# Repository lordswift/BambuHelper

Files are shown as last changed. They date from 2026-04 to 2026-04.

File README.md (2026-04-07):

# BambuHelper

Dedicated Bambu Lab printer monitor built with ESP32-S3 Super Mini and a 1.54" 240x240 color TFT display (ST7789).

Connects to your printer via MQTT over TLS and displays a real-time dashboard with arc gauges, animations, live stats, and optional buzzer notifications.

Beta support for CYD 320x240 displays is also available.

### Supported Printers

| Connection Mode | Printers | How it connects |
|---|---|---|
| **LAN Direct** | P1P, P1S, X1, X1C, X1E, A1, A1 Mini | Local MQTT via printer IP + LAN access code |
| **LAN Direct (Developer Mode)** | H2S, H2C, H2D | LAN-only mode + Developer Mode required - see note below |
| **Bambu Cloud (All printers)** | Any Bambu printer | Cloud MQTT via access token - no LAN mode needed |

> **H2 series LAN mode:** H2S, H2C, and H2D printers require both **LAN-only mode** and **Developer Mode** enabled in printer settings for local MQTT to work. Without Developer Mode, the printer accepts connections but does not respond to status requests. If you prefer not to enable Developer Mode, use Bambu Cloud mode instead.

> **Tip:** Use "Bambu Cloud (All printers)" if you don't want to enable LAN/Developer mode on your printer (for example to keep Bambu Handy working), if your ESP32 is on a different network than the printer, or if your printer only supports cloud mode (P2S).

### Cloud Mode Security Notice

When using Bambu Cloud, BambuHelper connects through Bambu Lab's cloud MQTT service. Here is what you need to know:

- **No credentials are stored** - BambuHelper never asks for your email or password. You extract an access token from your browser and paste it into the web interface.
- **Only the access token is stored** in the ESP32's flash memory. This token expires after about 3 months, at which point you simply paste a new one.
- **Read-only access** - BambuHelper only reads printer status. It never sends commands or modifies printer settings.
- **Same approach as other community projects** - this is the same authentication method used by the [Home Assistant Bambu Lab integration](https://github.com/greghesp/ha-bambulab), [OctoPrint-Bambu](https://github.com/jneilliii/OctoPrint-BambuPrinter), and other trusted third-party tools.

## Screenshots

| Dashboard | Web Interface - Settings | Web Interface - Gauge Colors |
|---|---|---|
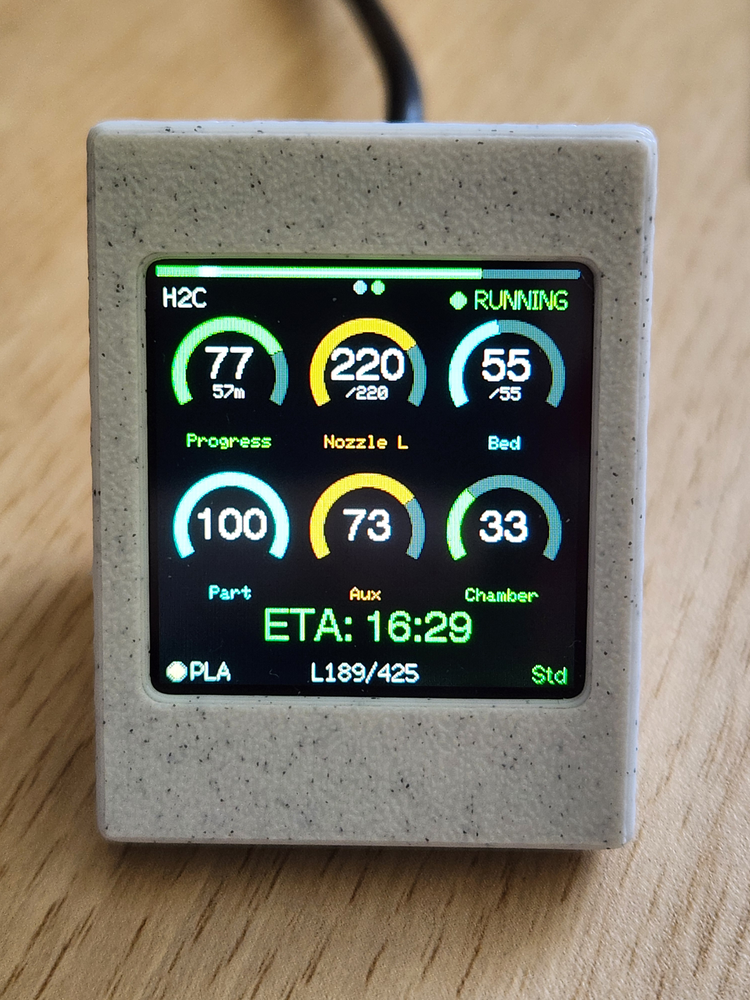
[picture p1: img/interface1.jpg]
Dashboard
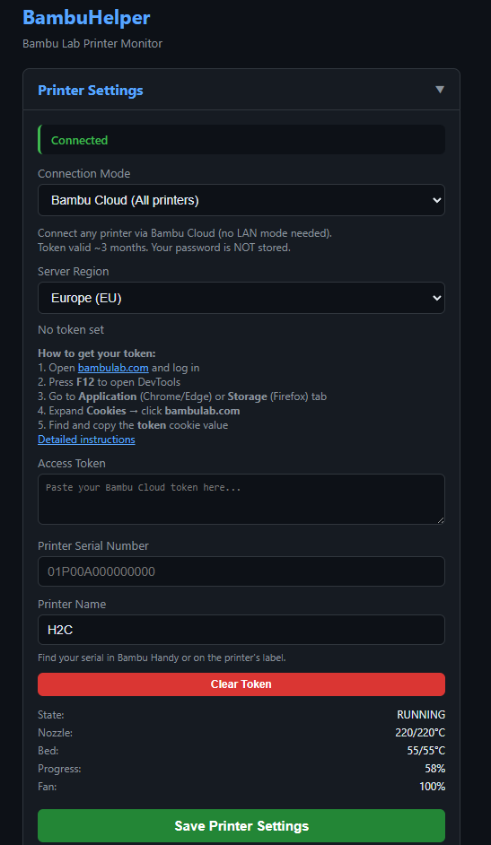
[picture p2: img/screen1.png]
Settings
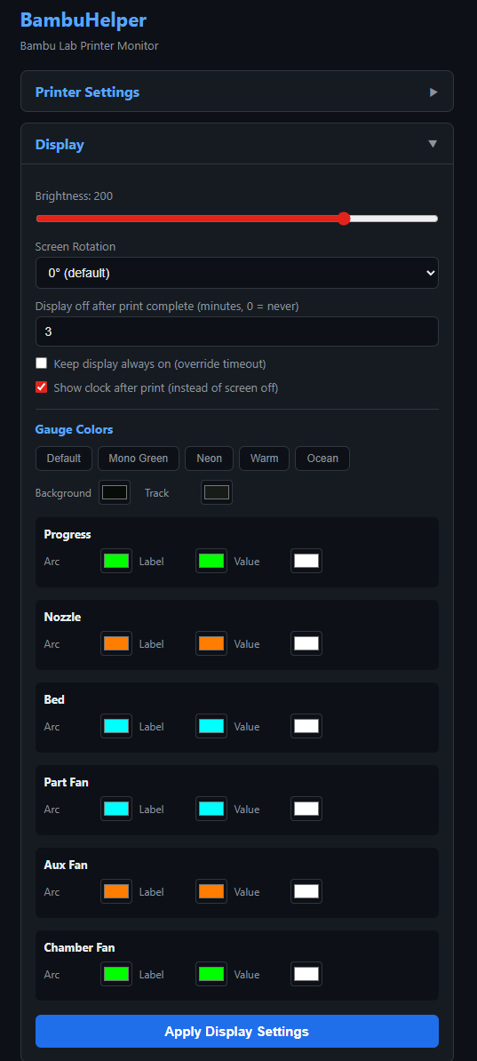
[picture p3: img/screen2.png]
Gauge Colors
|  |  |  |

## CYD Display Support (Beta)

| Preview | Notes |
|---|---|
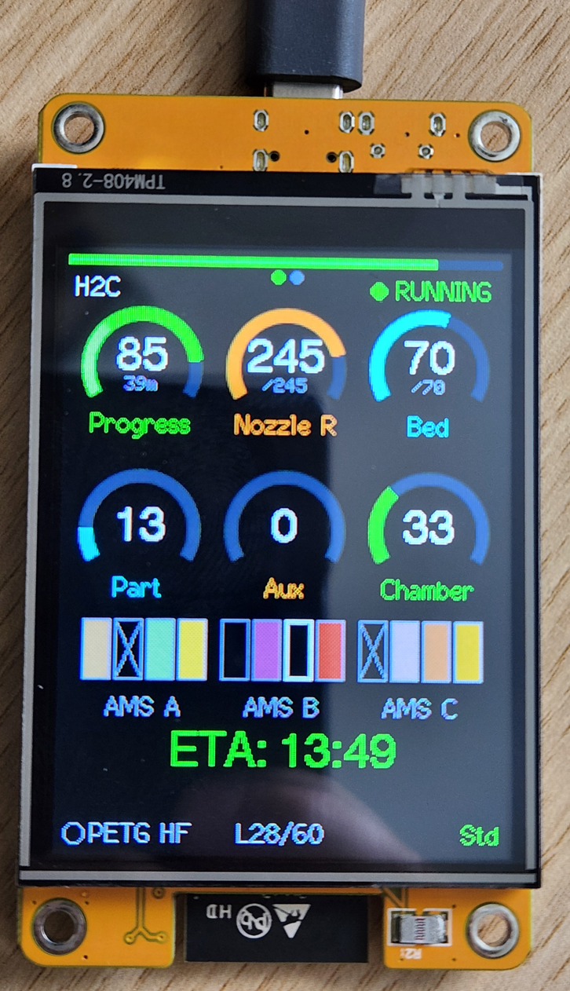
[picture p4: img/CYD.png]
CYD display
|  | **CYD / ESP32-2432S028** support is available and currently **beta**. This is the larger `320x240` display version. Flashing is done the same way as the standard `240x240` build, but on [ESP Web Flasher](https://espressif.github.io/esptool-js/) you should set **Baudrate: 115200** before clicking **Connect**. This low baudrate note is for **CYD only**. The standard ESP32-S3 240x240 version does not require this change. Tested behavior so far: The first connection attempt may fail - click **Disconnect** in the web tool, then **Connect** again and it should work on the second try. **Do not physically unplug the USB cable between attempts** - just use the buttons in the web flasher. [Use this firmware](https://github.com/Keralots/BambuHelper/releases/download/v2.5/BambuHelper-cyd-v2.5-Full.bin) If the display colors appear reversed (white background instead of dark), go to the web interface under **Display** and enable **Invert display colors (fix white background)**. |

## Features

- **Live dashboard** - progress arc, temperature gauges, fan speed, layer count, time remaining
- **H2-style LED progress bar** - full-width glowing bar inspired by Bambu H2 series
- **Anti-aliased arc gauges** - smooth nozzle and bed temperature arcs with color zones
- **Animations** - loading spinner, progress pulse, completion celebration
- **Web config portal** - dark-themed settings page for WiFi, network, printer, display, power, and buzzer settings
- **Network configuration** - DHCP or static IP, with optional IP display at startup
- **Display auto-off** - configurable timeout after print completion, auto-off when printer is off
- **NVS persistence** - all settings survive reboots
- **Auto AP mode** - creates WiFi hotspot on first boot or when WiFi is lost
- **Smart redraw** - only redraws changed UI elements for smooth performance
- **Customizable gauge colors** - per-gauge arc/label/value colors with preset themes
- **Multi-printer support** - monitor up to 2 printers simultaneously with auto-rotating display (ESP32-S3 only - CYD/C3 limited to 1 printer due to RAM)
- **Smart rotation** - automatically shows the printing printer; cycles between both when both are printing
- **Physical button** - optional push button or TTP223 touch sensor to cycle printers and wake display
- **Optional buzzer** - passive buzzer notifications for print finished, connected, and error events
- **OTA updates** - firmware can be updated from the web interface
- **CYD display support (beta)** - support for ESP32-2432S028 / 320x240 displays
- **Exponential backoff** - reconnect attempts to offline printers gradually slow down to conserve resources

## Hardware

| Component | Specification |
|---|---|
| MCU | ESP32-S3 Super Mini |
| Display | 1.54" TFT SPI ST7789 (240x240) |
| Optional display | CYD / ESP32-2432S028, 320x240 ILI9341 (beta) |
| Connection | SPI |

Display: 1.54": https://a.aliexpress.com/_EG9y7wc

ESP32-S3 SuperMini: https://a.aliexpress.com/_Eyk9GdA  (Make sure you purchase S3 variant!)

Optional: TTP223 touch button or standard push button for multi-printer switching (auto printer switching works without a button anyway; change settings in the web interface): TTP223 link: https://aliexpress.com/item/1005006246380749.html

Optional: Passive buzzer for print finish and error notifications: https://aliexpress.com/item/1005008825917787.html

Optional case seen on picture (for ST7789 (240x240) display): https://makerworld.com/en/models/2501721

### Default Wiring

| Display Pin ST7789 (240x240) | ESP32-S3 GPIO | ESP32-C3 GPIO |
|---|---|---|
| MOSI (SDA) | 11 | 20 |
| SCLK (SCL) | 12 | 21 |
| CS | 10 | 6 |
| DC | 9 | 7 |
| RST | 8 | 10 |
| BL | 13 | 5 |
| GND | GND | GND |
| VCC | 3.3V | 3.3V |

Adjust pin assignments in `platformio.ini` `build_flags` to match your wiring.

Touch TTP223 button is optional. It is used to switch between printers. You may also use a standard push button and connect it between pin 4 and GND, then pick the correct button type in the web interface under Multi-Printer support.

### Optional Touch Sensor / Button Wiring

A button or touch sensor is optional. It cycles between printers and wakes the display from sleep. Configure the type and GPIO in the web interface under **Multi-Printer**.

**TTP223 capacitive touch sensor:**

| TTP223 Pin | ESP32-S3 GPIO | ESP32-C3 GPIO |
|---|---|---|
| `VCC` | `3.3V` | `3.3V` |
| `GND` | `GND` | `GND` |
| `SIG` | `GPIO 4` | `GPIO 4` |

**Standard push button:** connect one leg to `GPIO 4` and the other to `GND`. The internal pull-up is enabled automatically. Select **Push Button** in the web interface.

### Optional Buzzer Wiring

The buzzer is completely optional. If you do not connect one, BambuHelper works normally.

Use a **passive buzzer** and connect it like this:

| Buzzer Pin | ESP32-S3 GPIO | ESP32-C3 GPIO |
|---|---|---|
| `+` / `SIG` | `GPIO 5` | `GPIO 3` |
| `-` / `GND` | `GND` | `GND` |

> **Note:** The firmware default buzzer pin is `GPIO 5` on both ESP32-S3 and ESP32-C3. The table above shows the **recommended wiring**. If you wire an ESP32-C3 buzzer to `GPIO 3`, you must change the buzzer pin to `GPIO 3` in the web interface after the first boot.
> **Note:** The firmware default buzzer pin is `GPIO 5` on both ESP32-S3 and ESP32-C3. The table above shows the **recommended wiring**. If you wire an ESP32-C3 buzzer to `GPIO 3`, you must change the buzzer pin to `GPIO 3` in the web interface after the first boot.
You can change the buzzer GPIO later in the web interface under **Buzzer**. The buzzer can be used for print-finished, connected, and error notifications.

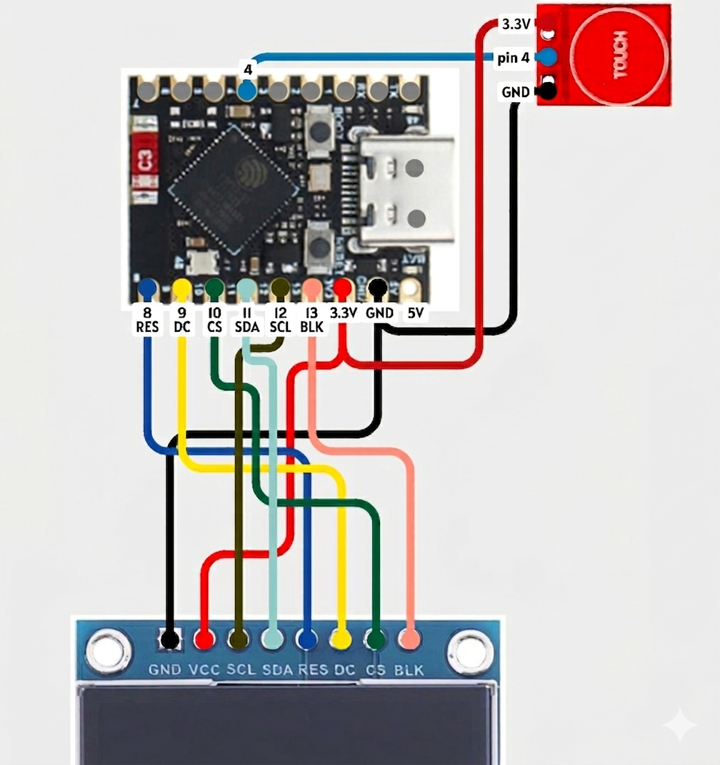
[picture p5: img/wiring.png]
wiring


### Assembly Video

Assembly Video (https://youtu.be/hsyamsU5UZE)

## Flashing

1. Download the latest firmware from [Releases](../../releases). **If you are flashing a new device for the first time**, use the file ending with **-Full** (e.g. `BambuHelper-WebFlasher-v2.5-Full.bin`). The regular (non-Full) file is for OTA updates on devices that already have BambuHelper installed.
2. Open [ESP Web Flasher](https://espressif.github.io/esptool-js/) in Chrome or Edge
3. If you are flashing a **CYD**, set **Baudrate** to **115200** before clicking **Connect**. Two or more attempts may be needed - the first one will fail. This applies to **CYD only**.
4. Connect your ESP32 via USB
5. Click **Connect** and select your device
6. Set flash address to **0x0**
7. Select the downloaded `.bin` file
8. Click **Program**

## Setup

### Configuration Guide

Configuration Guide (https://youtu.be/n2RdbeHTMz0)

1. **Flash** the firmware (see above)
2. **Connect** to the `BambuHelper-XXXX` WiFi network (password: `bambu1234`)
3. **Open** `192.168.4.1` in your browser
4. **Enter** your home WiFi credentials and **Save** - the device restarts and connects to your WiFi
5. **Note the IP address** shown on the ESP32 display after it connects to WiFi
6. **Open** that IP address in your browser to access the full web interface
7. **Configure your printer:**

   **LAN Direct** (P1P, P1S, X1, X1C, X1E, A1, A1 Mini):
   - Printer IP address (found in printer Settings > Network)
   - Serial number (see note below)
   - LAN access code (8 characters, from printer Settings > Network)

   **Bambu Cloud (All printers)**:
   - Get your Bambu Cloud access token from your browser (see [Getting a Cloud Token](#getting-a-cloud-token) below)
   - Paste the token into the web interface
   - Enter your printer's serial number (see note below)

   > **Important: Serial number is NOT the printer name.** The serial number is a 15-character code (for example `01P00A000000000`) found on the printer LCD under **Settings > Device > Serial Number**, or on the physical label on the back or bottom of the printer. Do not confuse it with the printer name shown in Bambu Studio (for example `3DP-01P-110`), which is a shortened version and will not work.

8. **Save Printer Settings** - the device connects to your printer

### Getting a Cloud Token

To use cloud mode, you need an access token from your Bambu Lab account. There are two ways to get it:

**Using browser DevTools (Chrome / Edge):**
1. Open https://bambulab.com and log in to your account
2. Press **F12** to open DevTools
3. Go to the **Application** tab (click `>>` if you do not see it)
4. In the left sidebar, expand **Cookies** -> click `https://bambulab.com`
5. Find the row named `token` in the cookie list
6. Double-click the **Value** cell to select it, then **Ctrl+C** to copy
7. Paste the value into BambuHelper's "Access Token" field in the web interface

**Using browser DevTools (Firefox):**
1. Open https://bambulab.com and log in to your account
2. Press **F12** to open DevTools
3. Go to the **Storage** tab
4. In the left sidebar, expand **Cookies** -> click `https://bambulab.com`
5. Find the row named `token`
6. Double-click the **Value** cell to select it, then **Ctrl+C** to copy
7. Paste the value into BambuHelper's "Access Token" field

**Using browser DevTools (Safari):**
1. Open https://bambulab.com and log in to your account
2. Open **Develop** -> **Show Web Inspector** (enable the Develop menu first in Safari Preferences -> Advanced)
3. Go to the **Storage** tab -> **Cookies** -> `bambulab.com`
4. Find and copy the `token` value
5. Paste it into BambuHelper's "Access Token" field

**Using the Python helper script (recommended):**
```bash
pip install curl_cffi
python tools/get_token.py
```
The script will prompt for your email, password, and 2FA code, then print the token. Copy and paste it into BambuHelper's web interface.

> **Note:** The token is valid for approximately 3 months. When it expires, the ESP32 will fail to connect - simply repeat the process above to get a fresh token and paste it in the web interface. Make sure to select the correct **Server Region** (US/EU/CN) to match your Bambu account's region.

## Web Interface

The built-in web interface (accessible at the device's IP address) provides the following settings:

### WiFi Settings
- **SSID** - your home WiFi network name
- **Password** - WiFi password

### Network
- **IP Assignment** - choose between DHCP (automatic) or Static IP
- **Static IP fields** (when static is selected):
  - IP Address
  - Gateway
  - Subnet Mask
  - DNS Server
- **Show IP at startup** - display the assigned IP on screen for 3 seconds after WiFi connects (on by default)

### Printer Settings
- **Connection Mode** - LAN Direct or Bambu Cloud (All printers)
- **LAN mode fields:**
  - Printer Name, Printer IP Address, Serial Number, LAN Access Code
- **Cloud mode fields:**
  - Server Region (US/EU/CN), Access Token, Printer Serial Number, Printer Name
- **Live Stats** - real-time nozzle/bed temp, progress, fan speed, and connection status

### Display
- **Brightness** - backlight level (10-255)
- **Screen Rotation** - 0, 90, 180, 270 degrees
- **Display off after print complete** - minutes to show the finish screen before turning off the display (0 = never turn off, default: 3 minutes)
- **Keep display always on** - override the timeout and never turn off
- **Show clock after print** - display a digital clock with date instead of turning off the screen (enabled by default)

### Gauge Colors
- **Theme presets** - Default, Mono Green, Neon, Warm, Ocean
- **Background color** - display background
- **Track color** - inactive arc background
- **Per-gauge colors** (arc, label, value) for:
  - Progress
  - Nozzle temperature
  - Bed temperature
  - Part fan
  - Aux fan
  - Chamber fan

### Buzzer
- **Buzzer (optional)** - enable or disable passive buzzer notifications
- **GPIO Pin** - choose which ESP32 pin drives the buzzer
- **Quiet Hours** - disable buzzer sounds during selected hours
- **Test Buttons** - quickly test available buzzer sounds from the web interface

### Other
- **Factory Reset** - erases all settings and restarts
- **OTA Update** - update firmware directly from the web interface

## Dashboard Screens

| Screen | When |
|---|---|
| Splash | Boot (2 seconds) |
| AP Mode | First boot / no WiFi configured |
| Connecting WiFi | Attempting WiFi connection |
| WiFi Connected | Shows IP for 3 seconds (if enabled) |
| Connecting Printer | WiFi connected, waiting for MQTT |
| Idle | Connected, printer not printing |
| Printing | Active print with full dashboard |
| Finished | Print complete with animation (auto-off after timeout) |
| Clock | After finish timeout (if enabled) - shows digital clock with date |
| Display Off | After finish timeout (if clock disabled) or printer powered off |

## Display Power Management

- After a print completes, the finish screen is shown for a configurable duration (default: 3 minutes), then either a digital clock is displayed or the screen turns off (configurable).
- When the printer is powered off or disconnected, the display stays in its current state (clock or off).
- When the printer comes back online or starts a new print, the display automatically wakes up.
- The "Keep display always on" option overrides the auto-off behavior.
- The "Show clock after print" option (enabled by default) shows time and date instead of turning off the display.

## Project Structure

```
include/
  config.h              Pin definitions, colors, constants
  bambu_state.h         Data structures (BambuState, PrinterConfig, ConnMode)
src/
  main.cpp              Setup/loop orchestrator
  settings.cpp          NVS persistence (WiFi, network, printer, display, power, cloud token)
  wifi_manager.cpp      WiFi STA + AP fallback, static IP support
  web_server.cpp        Config portal (HTML embedded, token management)
  bambu_mqtt.cpp        MQTT over TLS, delta merge (local + cloud broker)
  bambu_cloud.cpp       Bambu Cloud helpers (region URLs, JWT userId extraction)
  button.cpp            Physical button / touch sensor input
  buzzer.cpp            Optional passive buzzer support
  display_ui.cpp        Screen state machine
  display_gauges.cpp    Arc gauges, progress bar, temp gauges
  display_anim.cpp      Animations (spinner, pulse, dots)
  clock_mode.cpp        Digital clock display (after print finishes)
  icons.h               16x16 pixel-art icons
tools/
  get_token.py          Python helper to get Bambu Cloud token on PC
```

## Requirements

- [PlatformIO](https://platformio.org/) (VS Code extension or CLI)
- **LAN mode:** Bambu Lab printer with LAN mode enabled, printer and ESP32 on the same local network
- **Cloud mode:** Bambu Lab account, ESP32 with internet access

## Multi-Printer Monitoring

BambuHelper supports monitoring up to 2 printers simultaneously via dual MQTT connections.

> **CYD and ESP32-C3 boards are limited to 1 printer.** Each MQTT connection requires ~85 KB of RAM (TLS session + message buffer), and the classic ESP32 / C3 do not have enough free heap for two simultaneous connections. The web interface on these boards hides the second printer tab and shows a notice. Use an ESP32-S3 board if you need two printers.

### Rotation Modes

| Mode | Behavior |
|---|---|
| **Smart** (default) | Shows the printing printer. If both are printing, cycles between them. If neither is printing, shows last active. |
| **Auto-rotate** | Cycles through all connected printers at a configurable interval (10s - 10min). |
| **Off** | Manually switch between printers using the physical button only. |

### Physical Button

An optional physical button can be connected to cycle between printers and wake the display from sleep.

| Type | Wiring | How it works |
|---|---|---|
| **Push button** | One pin to configured GPIO, other pin to GND | Active LOW with internal pull-up |
| **TTP223 touch sensor** | VCC->3.3V, GND->GND, SIG->configured GPIO | Active HIGH |

The button type and GPIO pin are configurable in the web interface (Multi-Printer section) - no recompilation needed.

### MQTT Reconnect Backoff

When a printer is physically powered off, BambuHelper uses exponential backoff to avoid wasting resources on repeated connection attempts:

| Phase | Attempts | Interval |
|---|---|---|
| Normal | First 5 | Every 10 seconds |
| Phase 2 | Next 10 | Every 60 seconds |
| Phase 3 | Beyond 15 | Every 120 seconds |

When the printer comes back online, the backoff resets to normal immediately.

## Power Monitoring *(initial support, beta)*

| | |
|---|---|
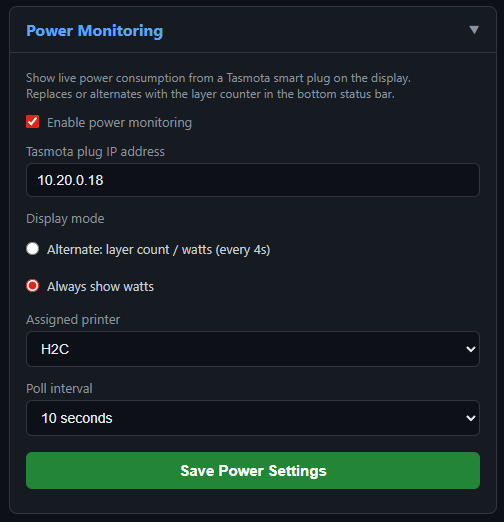
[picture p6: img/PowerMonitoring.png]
Power Monitoring
|  | BambuHelper can display live power consumption from a **[Tasmota](https://tasmota.github.io/docs/)-flashed smart plug** connected to your printer. Tasmota is open-source firmware for ESP-based smart plugs that exposes a local HTTP API and MQTT - no cloud required.<br><br>**What it shows:**<br>- Live wattage in the bottom status bar on the idle and printing screens<br>- Total kWh used during the print job, shown on the "Print Complete" screen<br><br>**Setup:** open the web interface, go to **Power Monitoring**, enter the plug's local IP address, set your preferred poll interval (10-30s), and choose whether to alternate the watts display with the layer counter or always show watts.<br><br>**Requirements:** any Tasmota-flashed smart plug with energy monitoring (e.g. Sonoff S31, BlitzWolf BW-SHP6, Nous A1). The plug must be on your local network and reachable from the ESP32. No Tasmota MQTT broker needed - BambuHelper polls the HTTP API directly.<br><br>*This is initial/beta support. Future plans include automatic printer power-off based on nozzle temperature and idle time.* |

## Troubleshooting

### WiFi won't connect / drops frequently

**SPI display cables near the ESP32 antenna can cause WiFi interference.** The ESP32-S3 Super Mini has a PCB antenna at one end of the board. If the SPI wires to the display run close to or over this antenna area, RF interference can prevent WiFi from connecting or cause frequent disconnections.

**Fix:** Route the display cables away from the antenna end of the ESP32-S3. Even 1-2 cm of separation can make a significant difference. If using a breadboard, ensure the wires do not loop back over the ESP32 module.

**Symptoms:**
- "Connecting to WiFi" screen appears briefly, then falls back to AP mode
- WiFi connects sometimes but drops after a few seconds
- Works fine when display is disconnected

**If WiFi issues persist**
Perform an antenna mod by soldering two individual goldpins to the antenna pads, as shown in the picture.



### Printer shows "Connecting" but never connects

- **LAN Direct:** Make sure the printer and ESP32 are on the same network. Check that LAN mode is enabled on the printer and the access code is correct.
- **Bambu Cloud:** Verify the access token has not expired (about 3 months validity). Re-extract it from your browser and paste it again. Check the server region matches your Bambu account.
- If a printer is physically powered off, reconnect attempts will gradually slow down (backoff). It will reconnect automatically when the printer comes back online.

### Display shows wrong printer / does not switch

- Check rotation mode in the web interface (Multi-Printer section). Smart mode only switches automatically when a printer is actively printing.
- Press the physical button (if configured) to manually cycle between printers.

## Future Plans

- Planned display support: Waveshare [ESP32-S3-LCD-1.54](https://www.waveshare.com/esp32-s3-lcd-1.54.htm) (240x240, ST7789)
- Planned display support: Waveshare [ESP32-S3-Touch-LCD-2](https://www.waveshare.com/esp32-s3-touch-lcd-2.htm) (240x320, ST7789T3 / CST816D touch)
- Automatic printer power-off via Tasmota after cooldown and idle timeout
- Expanded AMS/filament visualization

## License

MIT

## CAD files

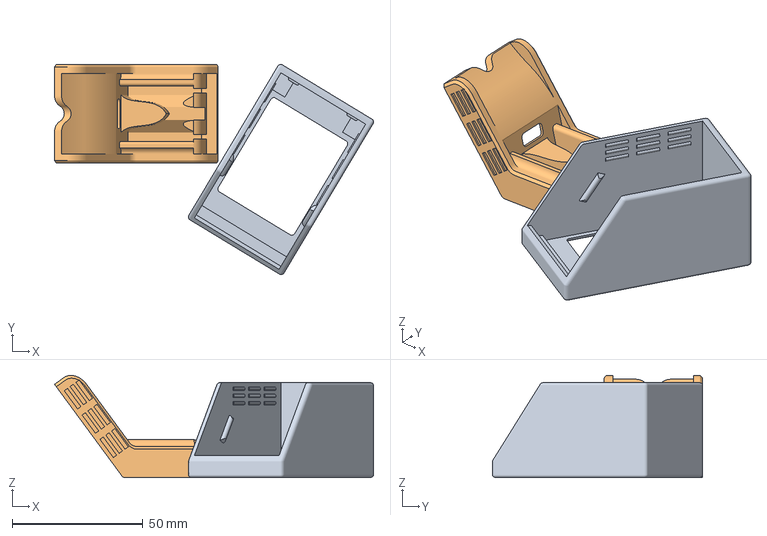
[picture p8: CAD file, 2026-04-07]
PrintProfile/TFT 1.8 full _v1.3mf
122.0 x 80.4 x 39.1 mm
MainBody.step
Back.step

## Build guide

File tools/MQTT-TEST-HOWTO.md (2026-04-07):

# Bambu MQTT Diagnostic Tool

Tests direct MQTT connection to your Bambu Lab printer in LAN mode.
Helps diagnose BambuHelper connection issues (State: UNKNOWN, no data, etc.)

## Setup (one-time)

1. Install Python from [python.org/downloads](https://www.python.org/downloads/)  - during install, check **"Add Python to PATH"**
2. Open Command Prompt (or Terminal on Mac) and run:
   ```
   pip install paho-mqtt
   ```

## Run the test

1. Open `mqtt_test.py` in Notepad and edit these 3 lines at the top with your printer info:
   ```python
   PRINTER_IP   = "YOUR_PRINTER_IP"       # e.g. "192.168.1.100"
   ACCESS_CODE  = "YOUR_ACCESS_CODE"      # 8 chars from printer LCD
   SERIAL       = "YOUR_SERIAL_NUMBER"    # MUST be UPPERCASE
   ```

   Where to find these values:
   - **IP address**: Printer LCD → Settings → Network
   - **Access Code**: Printer LCD → Settings → LAN Only Mode
   - **Serial Number**: Printer LCD → Settings → Device → Serial Number

2. Save the file, then in Command Prompt navigate to the folder and run:
   ```
   python mqtt_test.py
   ```

3. After 30 seconds it will show a summary:
   ```
   DIAGNOSTIC SUMMARY
   [PASS/FAIL] Serial number format
   [PASS/FAIL] TCP reachable
   [PASS/FAIL] TLS handshake
   [PASS/FAIL] MQTT auth
   [PASS/FAIL] Messages received
   ```

## What the results mean

| Result | Meaning |
|---|---|
| **TCP FAIL** | Printer not reachable  - check IP, same network, printer powered on |
| **TLS FAIL** | TLS handshake failed  - firewall or printer firmware issue |
| **MQTT auth FAIL (rc=4/5)** | Wrong Access Code  - re-check on printer LCD |
| **No messages** | Serial number mismatch  - MQTT topics are case-sensitive, serial MUST be uppercase |
| **All PASS** | Printer works fine  - issue is in BambuHelper config on the ESP |

## Sharing results

When reporting issues, please share:
- A screenshot of the full output (you can redact serial/access code)
- The `pushall_dump.json` file created in the same folder (if the test got data)

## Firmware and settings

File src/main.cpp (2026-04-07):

#include <Arduino.h>
#include "display_ui.h"
#include "settings.h"
#include "wifi_manager.h"
#include "web_server.h"
#include "bambu_mqtt.h"
#include "config.h"
#include "bambu_state.h"
#include "button.h"
#include "buzzer.h"
#include "tasmota.h"

static unsigned long splashEnd = 0;
static unsigned long finishScreenStart = 0;
static bool finishActive = false;          // guards finishScreenStart against millis() wrap
static unsigned long idleClockStart = 0;  // when all printers became idle
static bool idleClockActive = false;      // guards idleClockStart against millis() wrap
static unsigned long connectingScreenStart = 0;  // for stuck-state timeout
static char prevGcodeState[MAX_ACTIVE_PRINTERS][16] = {{0}};

static bool anyPrinterPrinting() {
  for (uint8_t i = 0; i < MAX_ACTIVE_PRINTERS; i++) {
    if (isPrinterConfigured(i) && printers[i].state.connected && printers[i].state.printing) {
      return true;
    }
  }
  return false;
}

static void transitionToClockOrOff() {
  if (dpSettings.showClockAfterFinish || buttonType == BTN_DISABLED) {
    setScreenState(SCREEN_CLOCK);
  } else {
    setScreenState(SCREEN_OFF);
  }
}

// ---------------------------------------------------------------------------
//  Display rotation logic (multi-printer)
// ---------------------------------------------------------------------------
static void handleRotation() {
  if (rotState.mode == ROTATE_OFF) return;
  if (getActiveConnCount() < 2) return;

  // Don't rotate when display is in clock, off, or finished state,
  // UNLESS a printer is actively printing (wake up to show it)
  ScreenState scr = getScreenState();
  if (scr == SCREEN_CLOCK || scr == SCREEN_OFF || scr == SCREEN_FINISHED) {
    if (!anyPrinterPrinting()) return;
    // A printer started printing — wake display and let rotation proceed
    setBacklight(getEffectiveBrightness());
  }

  unsigned long now = millis();
  if (now - rotState.lastRotateMs < rotState.intervalMs) return;

  // Gather candidates
  uint8_t candidates[MAX_ACTIVE_PRINTERS];
  uint8_t candidateCount = 0;
  uint8_t printingCount = 0;
  uint8_t printingSlot = 0xFF;

  for (uint8_t i = 0; i < MAX_ACTIVE_PRINTERS; i++) {
    if (!isPrinterConfigured(i)) continue;
    if (!printers[i].state.connected) continue;
    candidates[candidateCount++] = i;
    if (printers[i].state.printing) {
      printingCount++;
      printingSlot = i;
    }
  }

  if (candidateCount == 0) return;

  if (rotState.mode == ROTATE_SMART) {
    if (printingCount == 1) {
      // Only one printing — show it, no cycling
      if (rotState.displayIndex != printingSlot) {
        rotState.displayIndex = printingSlot;
        triggerDisplayTransition();
      }
      rotState.lastRotateMs = now;
      return;
    }
    // 0 or 2 printing: fall through to cycling
  }

  // Cycle to next candidate
  uint8_t current = rotState.displayIndex;
  for (uint8_t attempt = 1; attempt <= MAX_ACTIVE_PRINTERS; attempt++) {
    uint8_t next = (current + attempt) % MAX_ACTIVE_PRINTERS;
    for (uint8_t c = 0; c < candidateCount; c++) {
      if (candidates[c] == next && next != current) {
        rotState.displayIndex = next;
        triggerDisplayTransition();
        rotState.lastRotateMs = now;
        return;
      }
    }
  }

  rotState.lastRotateMs = now;
}

// ---------------------------------------------------------------------------
void setup() {
  Serial.begin(115200);
  Serial.printf("\n=== BambuHelper %s Starting ===\n", FW_VERSION);

  loadSettings();
  initDisplay();
  splashEnd = millis() + 2000;
  setBacklight(brightness);
}

void loop() {
  // Hold splash for 2s
  if (splashEnd > 0 && millis() > splashEnd) {
    splashEnd = 0;
    initWiFi();
    initWebServer();
    initBambuMqtt();
    initButton();
    initBuzzer();
    tasmotaInit();
  }

  if (splashEnd > 0) {
    delay(10);
    return;
  }

  handleWiFi();
  handleWebServer();

  if (isWiFiConnected() && !isAPMode()) {
    // Handle physical button press (before MQTT so screen wakes instantly
    // without waiting for a potentially blocking TLS reconnect)
    if (wasButtonPressed()) {
      buzzerPlayClick();
      ScreenState cur = getScreenState();
      if (cur == SCREEN_OFF || cur == SCREEN_CLOCK) {
        // Wake from sleep + reset backoff for immediate reconnect
        setBacklight(getEffectiveBrightness());
        finishActive = false;
        idleClockActive = false;
        resetMqttBackoff();
        deferMqttReconnect();  // skip blocking reconnect this iteration so screen wakes instantly
        setScreenState(SCREEN_IDLE);  // state machine will correct on next loop
      } else if (getActiveConnCount() >= 2) {
        // Cycle to next configured printer
        uint8_t idx = rotState.displayIndex;
        for (uint8_t a = 1; a <= MAX_ACTIVE_PRINTERS; a++) {
          uint8_t next = (idx + a) % MAX_ACTIVE_PRINTERS;
          if (isPrinterConfigured(next) && next != idx) {
            rotState.displayIndex = next;
            triggerDisplayTransition();
            rotState.lastRotateMs = millis();  // reset auto-rotate timer
            finishActive = false;
            // If switching to a cloud printer in UNKNOWN state, try a refresh
            requestCloudRefresh(next);
            break;
          }
        }
      } else if (cur == SCREEN_IDLE &&
                 isCloudMode(displayedPrinter().config.mode) &&
                 strcmp(displayedPrinter().state.gcodeState, "UNKNOWN") == 0) {
        // Single printer, cloud, UNKNOWN - manual refresh
        requestCloudRefresh(rotState.displayIndex);
      }
    }

    // Auto-select screen based on displayed printer state
    BambuState& s = displayedPrinter().state;
    ScreenState current = getScreenState();

    if (!isAnyPrinterConfigured()) {
      if (current != SCREEN_IDLE && current != SCREEN_OFF) {
        setScreenState(SCREEN_IDLE);
        finishActive = false;
      }
    } else if (isOtaAutoInProgress()) {
      if (current != SCREEN_OTA_UPDATE) setScreenState(SCREEN_OTA_UPDATE);
    } else if (!s.connected && current != SCREEN_CONNECTING_MQTT &&
               current != SCREEN_OFF && current != SCREEN_CLOCK) {
      setScreenState(SCREEN_CONNECTING_MQTT);
      finishActive = false;
      connectingScreenStart = millis();
    } else if (!s.connected && (current == SCREEN_OFF || current == SCREEN_CLOCK)) {
      // Stay off/clock when printer is disconnected/off
    } else if (s.connected && s.printing) {
      if (current != SCREEN_PRINTING) {
        setScreenState(SCREEN_PRINTING);
        finishActive = false;
        if (tasmotaSettings.assignedSlot == 255 ||
            tasmotaSettings.assignedSlot == rotState.displayIndex)
          tasmotaMarkPrintStart();
      }
      s.finishBuzzerPlayed = false;  // reset for next finish event
      s.doorAcknowledged = false;    // reset door ack for next finish
    } else if (s.connected && !s.printing &&
               strcmp(s.gcodeState, "FINISH") == 0) {
      if (current != SCREEN_FINISHED && current != SCREEN_OFF && current != SCREEN_CLOCK) {
        if (tasmotaSettings.enabled &&
            (tasmotaSettings.assignedSlot == 255 ||
             tasmotaSettings.assignedSlot == rotState.displayIndex))
          tasmotaMarkPrintEnd();
        setScreenState(SCREEN_FINISHED);
        finishScreenStart = millis();
        finishActive = true;
        if (!s.finishBuzzerPlayed) {
          buzzerPlay(BUZZ_PRINT_FINISHED);
          s.finishBuzzerPlayed = true;
        }
      }

      // Door acknowledge: wait for door open before starting timeout
      bool waitingForDoor = dpSettings.doorAckEnabled && s.doorSensorPresent
                            && !s.doorAcknowledged;
      if (waitingForDoor && s.doorOpen) {
        s.doorAcknowledged = true;
        finishScreenStart = millis();  // restart timeout from door open moment
        finishActive = true;
        Serial.println("Door opened - print removal acknowledged, starting timeout");
      }
    } else if (s.connected && !s.printing &&
               strcmp(s.gcodeState, "FINISH") != 0) {
      // SCREEN_CLOCK and SCREEN_OFF are sticky — only button press or
      // new print (s.printing → SCREEN_PRINTING) exits them
      if (current == SCREEN_CLOCK || current == SCREEN_OFF) {
        // nothing — stay asleep while printer is idle
      } else if (current != SCREEN_IDLE) {
        if (current == SCREEN_CONNECTING_MQTT) buzzerPlay(BUZZ_CONNECTED);
        setScreenState(SCREEN_IDLE);
        finishActive = false;
        idleClockActive = false;
      }
    }
  }

  // Idle/Connecting → Clock/Off: if all printers are idle or disconnected,
  // transition to clock or off after finishDisplayMins timeout.
  // Covers both SCREEN_IDLE (printer connected but not printing) and
  // SCREEN_CONNECTING_MQTT (printer offline/unreachable at startup).
  ScreenState cur = getScreenState();
  if (cur == SCREEN_FINISHED && !dpSettings.keepDisplayOn && finishActive) {
    BambuState& fs = displayedPrinter().state;
    bool waitingForDoor = dpSettings.doorAckEnabled && fs.doorSensorPresent &&
                          !fs.doorAcknowledged;
    if (!waitingForDoor) {
      bool timeoutReached = (dpSettings.finishDisplayMins > 0) &&
          (millis() - finishScreenStart > (unsigned long)dpSettings.finishDisplayMins * 60000UL);
      bool immediateClockTransition = (dpSettings.finishDisplayMins == 0) &&
          (dpSettings.showClockAfterFinish || buttonType == BTN_DISABLED);
      if ((timeoutReached || immediateClockTransition) && !anyPrinterPrinting()) {
        transitionToClockOrOff();
        finishActive = false;
      }
    }
  }

  if ((cur == SCREEN_IDLE || cur == SCREEN_CONNECTING_MQTT) &&
      !dpSettings.keepDisplayOn && dpSettings.finishDisplayMins > 0) {
    if (!anyPrinterPrinting()) {
      if (!idleClockActive) { idleClockStart = millis(); idleClockActive = true; }
      if (millis() - idleClockStart > (unsigned long)dpSettings.finishDisplayMins * 60000UL) {
        transitionToClockOrOff();
      }
    } else {
      idleClockActive = false;
    }
  } else if (cur != SCREEN_IDLE && cur != SCREEN_CONNECTING_MQTT) {
    idleClockActive = false;
  }

  // Stuck-state timeout: recover if stuck in a connecting screen too long
  {
    ScreenState curConn = getScreenState();
    if (curConn == SCREEN_CONNECTING_WIFI || curConn == SCREEN_CONNECTING_MQTT) {
      if (connectingScreenStart == 0) connectingScreenStart = millis();
      if (millis() - connectingScreenStart > DISPLAY_STATE_TIMEOUT_MS) {
        Serial.println("[MAIN] State timeout, recovering from connecting screen");
        connectingScreenStart = 0;
        if (dpSettings.showClockAfterFinish) {
          setScreenState(SCREEN_CLOCK);
        } else {
          setScreenState(SCREEN_IDLE);
        }
      }
    } else {
      connectingScreenStart = 0;
    }
  }

  // Check for error state transition on any printer
  for (uint8_t i = 0; i < MAX_ACTIVE_PRINTERS; i++) {
    if (!isPrinterConfigured(i)) continue;
    BambuState& ps = printers[i].state;
    if (strcmp(ps.gcodeState, "FAILED") == 0 &&
        strcmp(prevGcodeState[i], "FAILED") != 0 &&
        prevGcodeState[i][0] != '\0') {
      buzzerPlay(BUZZ_ERROR);
    }
    strlcpy(prevGcodeState[i], ps.gcodeState, sizeof(prevGcodeState[i]));
  }

  buzzerTick();
  checkNightMode();
  updateDisplay();

  // MQTT and rotation after display update - TLS reconnect can block for
  // several seconds so we handle it last to keep UI responsive
  if (isWiFiConnected() && !isAPMode() && isAnyPrinterConfigured()) {
    handleBambuMqtt();
    handleRotation();
  }
}

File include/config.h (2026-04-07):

#ifndef CONFIG_H
#define CONFIG_H

// =============================================================================
//  Firmware version
// =============================================================================
#define FW_VERSION          "v2.6"

// Board variant — injected into the web UI for OTA asset filtering.
// Normally set via build_flags in platformio.ini; this is a fallback.
#ifndef BOARD_VARIANT
#define BOARD_VARIANT       "esp32s3"
#endif

// =============================================================================
//  Display
// =============================================================================
#include "layout.h"
#define SCREEN_W        LY_W
#define SCREEN_H        LY_H
#define BACKLIGHT_PIN   TFT_BL  // set by build flags per board
#define BACKLIGHT_CH    0
#define BACKLIGHT_FREQ  5000
#define BACKLIGHT_RES   8

// =============================================================================
//  Color palette (RGB565)
// =============================================================================
#define CLR_BG          0x0000   // black
#define CLR_CARD        0x1926   // dark card bg
#define CLR_HEADER      0x10A2   // header bar bg
#define CLR_TEXT         0xFFFF   // white
#define CLR_TEXT_DIM     0xC618   // gray text
#define CLR_TEXT_DARK    0x7BEF   // darker gray
#define CLR_GREEN        0x07E0   // bright green
#define CLR_GREEN_DARK   0x0400   // dark green (track)
#define CLR_BLUE         0x34DF   // accent blue
#define CLR_ORANGE       0xFBE0   // nozzle accent
#define CLR_CYAN         0x07FF   // bed accent
#define CLR_RED          0xF800   // error / hot
#define CLR_YELLOW       0xFFE0   // pause / warm
#define CLR_GOLD         0xFEA0   // progress near done
#define CLR_TRACK        0x18E3   // arc background track

// =============================================================================
//  MQTT / Bambu
// =============================================================================
#define BAMBU_PORT                  8883
#define BAMBU_USERNAME              "bblp"
#define BAMBU_BUFFER_SIZE           40960   // 40KB - H2C with 3 AMS sends ~33KB
#define BAMBU_RECONNECT_INTERVAL    10000   // 10s between attempts
#define BAMBU_BACKOFF_PHASE1        5       // first N attempts at normal interval
#define BAMBU_BACKOFF_PHASE2_MS     60000   // 60s after phase 1 exhausted
#define BAMBU_BACKOFF_PHASE2        10      // next N attempts at phase 2 interval
#define BAMBU_BACKOFF_PHASE3_MS     120000  // 120s after phase 2 exhausted
#define BAMBU_STALE_TIMEOUT         60000   // 60s no data = stale
#define BAMBU_PUSHALL_INTERVAL      30000   // request full status every 30s
#define BAMBU_PUSHALL_INITIAL_DELAY 2000    // wait 2s after connect
#define BAMBU_MIN_FREE_HEAP         40000   // min heap for TLS allocation
#define BAMBU_KEEPALIVE             60

// =============================================================================
//  WiFi
// =============================================================================
#define WIFI_AP_PREFIX      "BambuHelper-"
#define WIFI_AP_PASSWORD    "bambu1234"
#define WIFI_CONNECT_TIMEOUT 15000  // 15s STA connect timeout
#define WIFI_RECONNECT_TIMEOUT 60000 // 60s before re-entering AP mode
#define WIFI_BACKOFF_PHASE1_MS    10000   // 10s between attempts in phase 1
#define WIFI_BACKOFF_PHASE2_MS    30000   // 30s between attempts after phase 1
#define WIFI_BACKOFF_PHASE3_MS    60000   // 60s between attempts after phase 2
#define WIFI_BACKOFF_PHASE2_START 5       // start phase 2 after this many attempts
#define WIFI_BACKOFF_PHASE3_START 10      // start phase 3 after this many attempts
#define WIFI_STA_PROBE_INTERVAL   120000  // 2 min between STA probes while in AP mode
#define WIFI_STA_PROBE_CHECK_MS    10000  // 10s after probe start before checking result
#define WIFI_AP_FALLBACK_MS       900000  // 15 min in phase 3 before falling back to AP

// =============================================================================
//  NVS
// =============================================================================
#define NVS_NAMESPACE       "bambu"

// =============================================================================
//  Multi-printer
// =============================================================================
#define MAX_PRINTERS          4       // NVS config slots
#define MAX_ACTIVE_PRINTERS   2       // max simultaneous MQTT connections

// =============================================================================
//  Display rotation (multi-printer)
// =============================================================================
#define ROTATE_INTERVAL_MS    60000   // default auto-rotate: 1 min
#define ROTATE_MIN_MS         10000   // min allowed interval (10s)
#define ROTATE_MAX_MS         600000  // max allowed interval (10 min)
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
